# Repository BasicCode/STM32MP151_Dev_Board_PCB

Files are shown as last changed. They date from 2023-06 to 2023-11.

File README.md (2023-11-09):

# STM32MP151 Dev Board
**Rev B**
  
**NOTE: There are issues with this board. The WiFi, and the sound do not work (yes, that's basically all of the peripherals).**
  
**NOTE:** I have moved on from this project and it is no longer maintained. You can find some progress on my [STM32MP135 board](https://github.com/BasicCode/STM32MP135_Dev_Board_Buildroot).

A *minimal* STM32MP151 single-board-computer PCB, designed in KiCad, based on a [MYiR SoM](https://au.mouser.com/ProductDetail/MYIR/MYC-YA151C-256N256D-65-C-T?qs=e8oIoAS2J1SxKfhSw3h3gA%3D%3D). This project is intended as a minimal implementation of an ARM based Linux system used for learning Buildroot, the Linux kernel, the device tree system, and PCB design. The design uses hand-solderable parts (intermediate skill level), a 2-layer PCB design which can be manufactured by any PCB manufacturer, and a minimal set of peripherals.
  
**NOTE** that this project is a learning process and I a have no professional experience with PCB layout - don't use this as a reference design. That said, if it works for your purpose, please feel free to modify or use it.

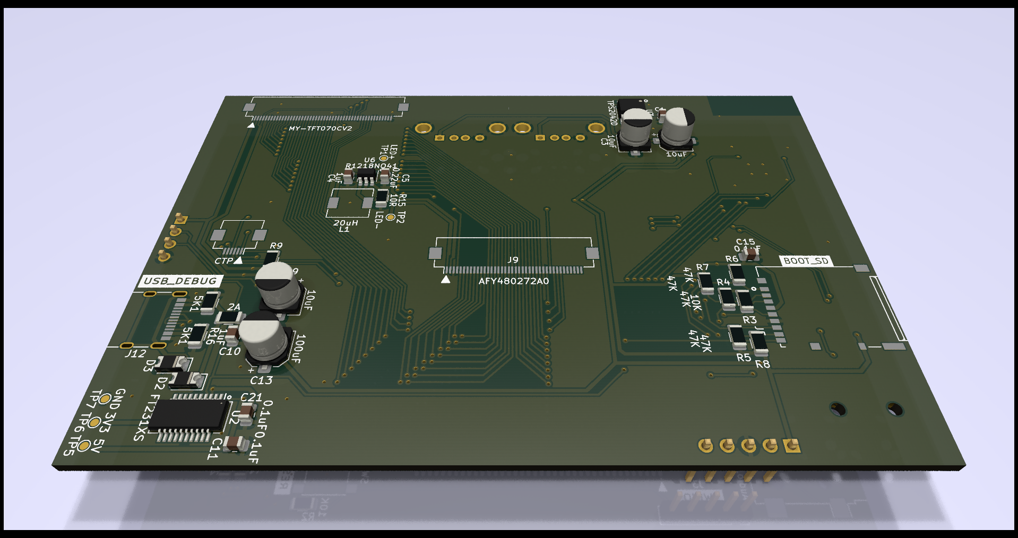
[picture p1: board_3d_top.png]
Citcuit Board

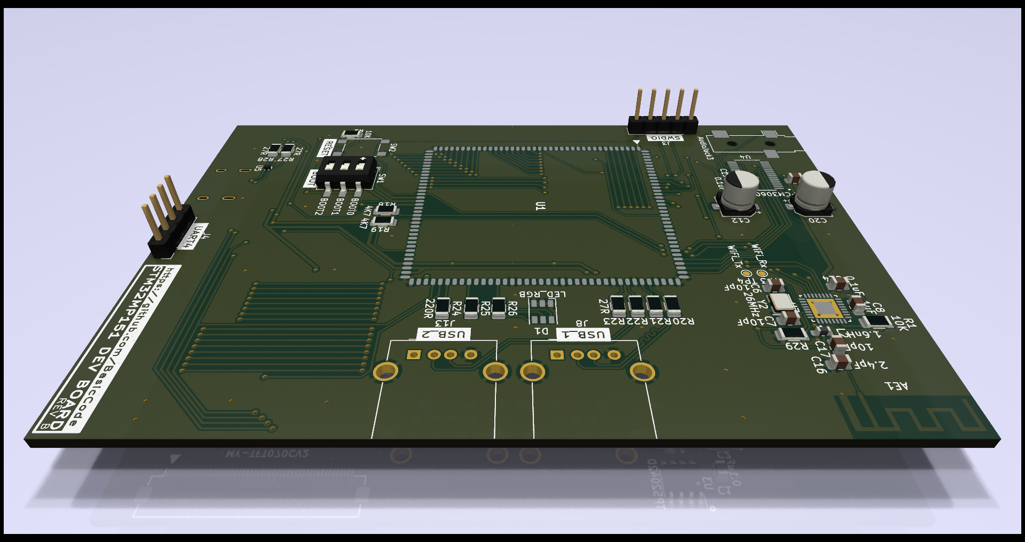
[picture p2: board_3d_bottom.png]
Circuit Board


## Software

* [Buildroot external tree](https://github.com/BasicCode/STM32MP15x_Dev_Board)

## Hardware

* [Schematic](schematic.pdf)
* [PCB available from OSH Park](https://oshpark.com/shared_projects/CuSocwHZ)
* [Parts list](https://www.digikey.com.au/en/mylists/list/Z7PZFZ0LWC)

### Specifications
* STM32MP151 ARM Cortex A7 running at 650MHz
* 256MB DDR3 RAM
* 256MB NAND Flash (not used in this example)
* 4.3-inch, OR 7-inch LCD with touch
* 2x USB 2.0 host ports
* USB-C power and serial port
* Wifi
* 3.5mm Audio Out

### Parts
A parts list is available on Digikey with **most** of the components, as well as the included [BoM file](STM32MP151_Dev_Board.csv). Please double check the Digikey parts list against the BoM before ordering, in case some components are missing. The [MYiR SoM](https://au.mouser.com/ProductDetail/MYIR/MYC-YA151C-256N256D-65-C-T?qs=e8oIoAS2J1SxKfhSw3h3gA%3D%3D) is only available from Mouser or directly from the manufacturer.

## Assembly
Components can be soldered by hand with some difficulty and patience. Some peripherals which are more difficult to solder (like WiFi), or not needed, can be left unpopulated. The minimum working example for this system is just the system-on-module, and the *UART* or *SWDIO* header, however this isn't very useful or interesting and so the other peripherals are included for fun.

## Bugs
* WiFi chipset doesn't seem to work. I believe it is connected correctly, Linux seems to recognise the chip and attempt to load the driver, however the driver fails to load.
* The PCM3060 audio chipset has not been tested yet. May not even work.

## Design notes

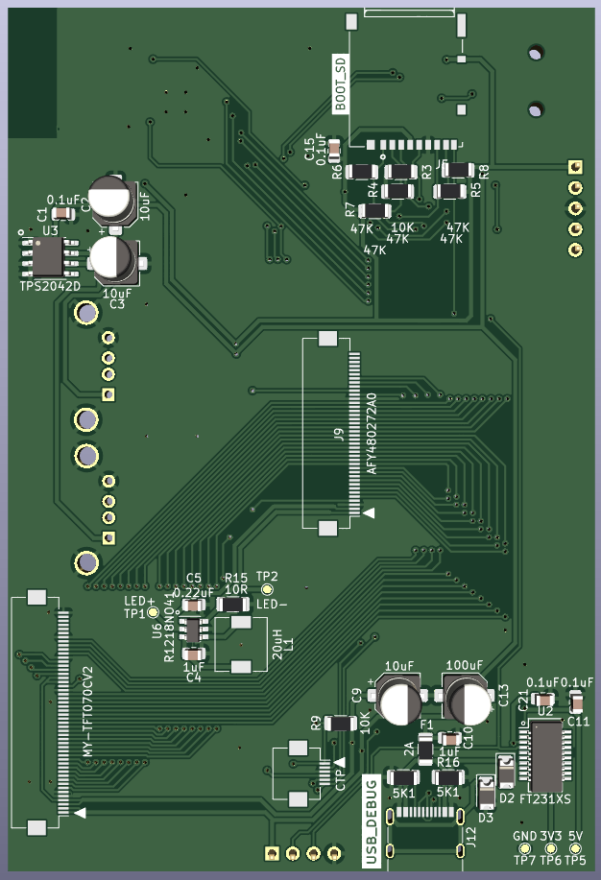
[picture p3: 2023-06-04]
board_top.png

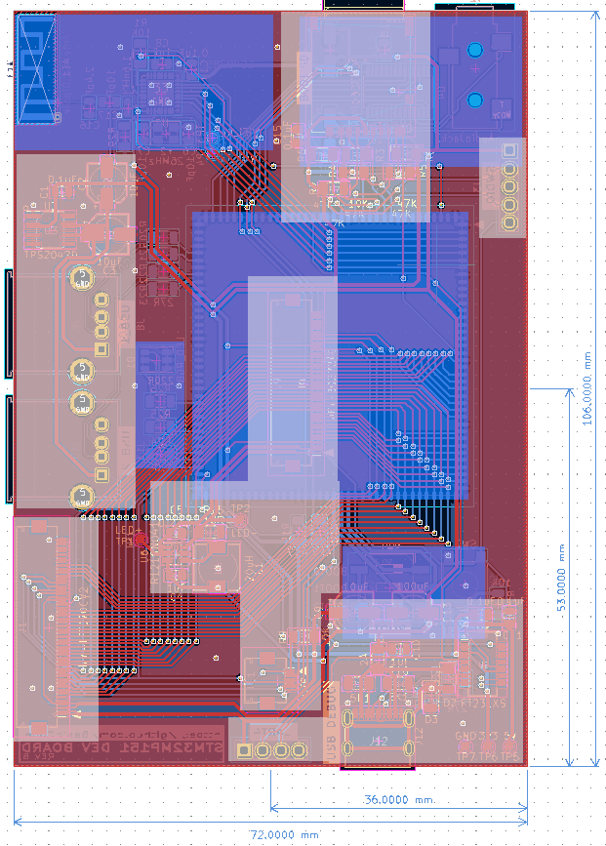
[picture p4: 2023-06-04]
board_map.png

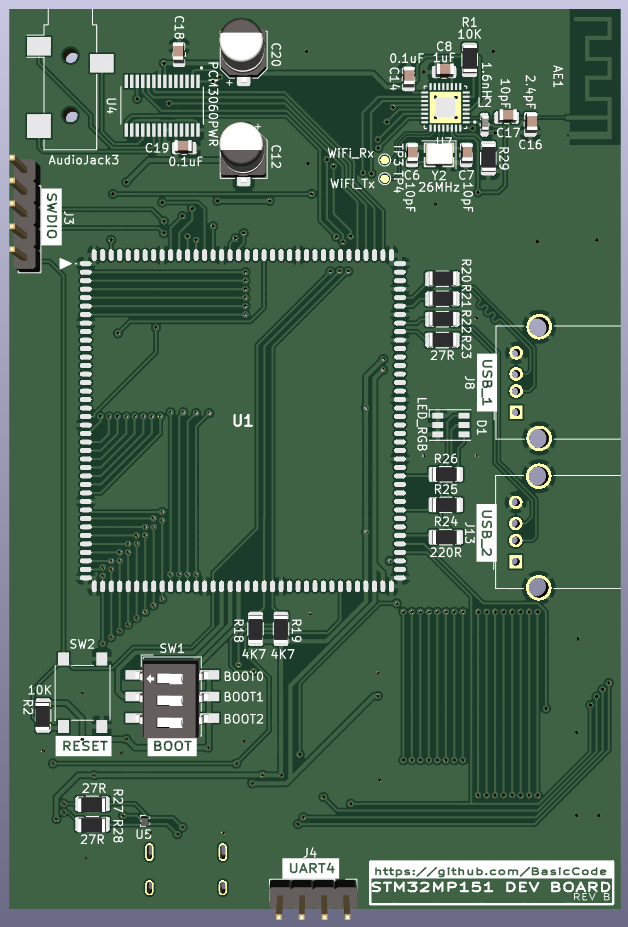
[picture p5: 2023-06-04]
board_bottom.png

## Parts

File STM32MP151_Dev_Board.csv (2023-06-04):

Source: | C:\Users\tommy\OneDrive\Documents\KiCad\STM32MP151_Dev_Board_RevB\STM32MP151_Dev_Board.kicad_sch
Date: | 3/06/2023 5:22:46 PM
Tool: | Eeschema 7.0.1
Generator: | C:\Program Files\KiCad\7.0\bin\scripting\plugins/bom_csv_grouped_by_value_with_fp.py
Component Count: | 79
Ref | Qnty | Value | Cmp name | Footprint | Description | Vendor | DNP
AE1 | 1 | Antenna_Dipole | Antenna_Dipole | RF_Antenna:Texas_SWRA117D_2.4GHz_Left | Dipole antenna
C1, C11, C14, C15, C18, C19, C21 | 7 | 0.1uF | C | Capacitor_SMD:C_0805_2012Metric | Unpolarized capacitor
C2, C3, C9, C12, C20 | 5 | 10uF | C_Polarized | Capacitor_SMD:CP_Elec_5x5.3 | Polarized capacitor
C4, C8, C10 | 3 | 1uF | C | Capacitor_SMD:C_0805_2012Metric | Unpolarized capacitor
C5 | 1 | 0.22uF | C | Capacitor_SMD:C_0805_2012Metric | Unpolarized capacitor
C6, C7, C17 | 3 | 10pF | C | Capacitor_SMD:C_0805_2012Metric | Unpolarized capacitor
C13 | 1 | 100uF | C_Polarized | Capacitor_SMD:CP_Elec_5x5.3 | Polarized capacitor
C16 | 1 | 2.4pF | C | Capacitor_SMD:C_0805_2012Metric | Unpolarized capacitor
D1 | 1 | LED_RGB | LED_RGB | LED_SMD:LED_RGB_PLCC-6 | RGB LED, 6 pin package
D2, D3 | 2 | TVS | D_Schottky | Diode_SMD:D_1206_3216Metric | Schottky diode
F1 | 1 | 2A | Polyfuse | Fuse:Fuse_1206_3216Metric | Resettable fuse, polymeric positive temperature coefficient
J1 | 1 | MY-TFT070CV2 | Conn_02x25_Odd_Even | Connector_FFC-FPC:Hirose_FH12-50S-0.5SH_1x50-1MP_P0.50mm_Horizontal | Generic connector, double row, 02x25, odd/even pin numbering scheme (row 1 odd numbers, row 2 even numbers), script generated (kicad-library-utils/schlib/autogen/connector/)
J2 | 1 | AudioJack3 | AudioJack3 | Connector_Audio:Jack_3.5mm_CUI_SJ-3523-SMT_Horizontal | Audio Jack, 3 Poles (Stereo / TRS)
J3 | 1 | SWDIO | Conn_01x05_Pin | Connector_PinHeader_2.54mm:PinHeader_1x05_P2.54mm_Vertical | Generic connector, single row, 01x05, script generated
J4 | 1 | UART4 | Conn_01x04_Pin | Connector_PinHeader_2.54mm:PinHeader_1x04_P2.54mm_Vertical | Generic connector, single row, 01x04, script generated
J5 | 1 | BOOT_SD | DM3AT-SF-PEJM5 | MYC_YA151:HRS_DM3AT-SF-PEJM5
J8 | 1 | USB_1 | USB_A | Connector_USB:USB_A_Molex_67643_Horizontal | USB Type A connector
J9 | 1 | AFY480272A0 | Conn_01x40 | Connector_FFC-FPC:Hirose_FH12-40S-0.5SH_1x40-1MP_P0.50mm_Horizontal | Generic connector, single row, 01x40, script generated (kicad-library-utils/schlib/autogen/connector/)
J11 | 1 | CTP | Conn_01x06 | Connector_FFC-FPC:Hirose_FH12-6S-0.5SH_1x06-1MP_P0.50mm_Horizontal | Generic connector, single row, 01x06, script generated (kicad-library-utils/schlib/autogen/connector/)
J12 | 1 | USB_DEBUG | USB_C_Receptacle_USB2.0 | Connector_USB:USB_C_Receptacle_G-Switch_GT-USB-7010ASV | USB 2.0-only Type-C Receptacle connector
J13 | 1 | USB_2 | USB_A | Connector_USB:USB_A_Molex_67643_Horizontal | USB Type A connector
L1 | 1 | 20uH | L | Inductor_SMD:L_6.3x6.3_H3 | Inductor
L2 | 1 | 1.6nH | L | Inductor_SMD:L_0603_1608Metric_Pad1.05x0.95mm_HandSolder | Inductor
R1, R2, R3, R9 | 4 | 10K | R | Resistor_SMD:R_1206_3216Metric | Resistor
R4, R5, R6, R7, R8 | 5 | 47K | R | Resistor_SMD:R_1206_3216Metric | Resistor
R15 | 1 | 10R | R | Resistor_SMD:R_1206_3216Metric | Resistor
R16, R17 | 2 | 5K1 | R | Resistor_SMD:R_1206_3216Metric | Resistor
R18, R19 | 2 | 4K7 | R | Resistor_SMD:R_1206_3216Metric | Resistor
R20, R21, R22, R23, R27, R28 | 6 | 27R | R | Resistor_SMD:R_1206_3216Metric | Resistor
R24, R25, R26 | 3 | 220R | R | Resistor_SMD:R_1206_3216Metric | Resistor
R29 | 1 | 12K | R | Resistor_SMD:R_1206_3216Metric | Resistor
SW1 | 1 | BOOT | SW_DIP_x03 | Button_Switch_SMD:SW_DIP_SPSTx03_Slide_6.7x9.18mm_W8.61mm_P2.54mm_LowProfile | 3x DIP Switch, Single Pole Single Throw (SPST) switch, small symbol
SW2 | 1 | RESET | SW_Push | Button_Switch_SMD:SW_Push_1P1T_NO_6x6mm_H9.5mm | Push button switch, generic, two pins
TP1 | 1 | LED+ | TestPoint | TestPoint:TestPoint_Pad_D1.0mm | test point
TP2 | 1 | LED- | TestPoint | TestPoint:TestPoint_Pad_D1.0mm | test point
TP3 | 1 | WiFi_Rx | TestPoint | TestPoint:TestPoint_Pad_D1.0mm | test point
TP4 | 1 | WiFi_Tx | TestPoint | TestPoint:TestPoint_Pad_D1.0mm | test point
TP5 | 1 | 5V | TestPoint | TestPoint:TestPoint_Pad_D1.0mm | test point
TP6 | 1 | 3V3 | TestPoint | TestPoint:TestPoint_Pad_D1.0mm | test point
TP7 | 1 | GND | TestPoint | TestPoint:TestPoint_Pad_D1.0mm | test point
U1 | 1 | MYC-YA151C-256N256D | MYC-YA151C-256N256D-65-C-T | MYC_YA151:MYCYA151C256N256D65CT | Embedded Module ARM Cortex-A7, ARM Cortex-M4 650MHz 256MB 256MB
U2 | 1 | FT231XS | FT231XS | Package_SO:SSOP-20_3.9x8.7mm_P0.635mm | Full Speed USB to Full Handshake UART, SSOP-20
U3 | 1 | TPS2042D | TPS2042D | Package_SO:SOIC-8_3.9x4.9mm_P1.27mm | Dual power-distribution switcher
U4 | 1 | PCM3060PWR | PCM3060PWR | PCM3060:SOP65P640X120-28N
U5 | 1 | TPD2EUSB30 | TPD2EUSB30 | Package_TO_SOT_SMD:Texas_DRT-3 | 2-Channel ESD Protection for Super-Speed USB 3.0 Interface, DRT-3
U6 | 1 | R1218NO41 | Conn_02x03_Counter_Clockwise | Package_TO_SOT_SMD:SOT-23-6 | Generic connector, double row, 02x03, counter clockwise pin numbering scheme (similar to DIP package numbering), script generated (kicad-library-utils/schlib/autogen/connector/)
U7 | 1 | ESP8285 | ESP8285 | esp8285:QFN50P500X500X90-33N
Y2 | 1 | 26MHz | Crystal_GND24 | Crystal:Crystal_SMD_3225-4Pin_3.2x2.5mm | Four pin crystal, GND on pins 2 and 4

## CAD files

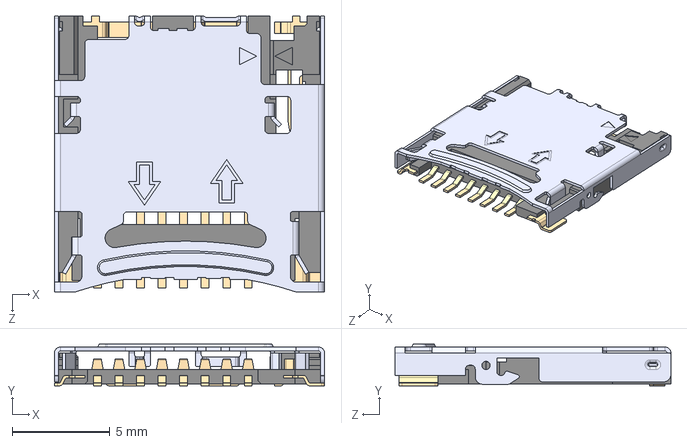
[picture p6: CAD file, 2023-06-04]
components/DM3CS-SF.step
13.8 x 2.13 x 14.1 mm

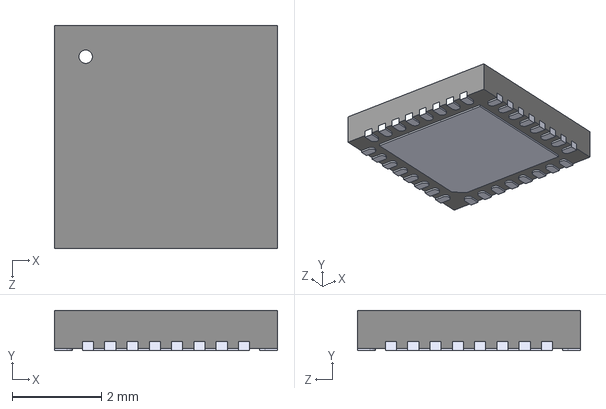
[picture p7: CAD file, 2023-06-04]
components/ESP8285.step
5.00 x 0.9 x 5.00 mm

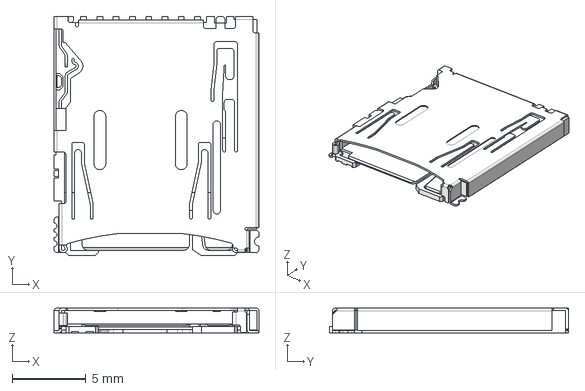
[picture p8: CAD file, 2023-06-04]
components/DM3AT-SF-PEJM5.step
13.8 x 16.2 x 1.68 mm

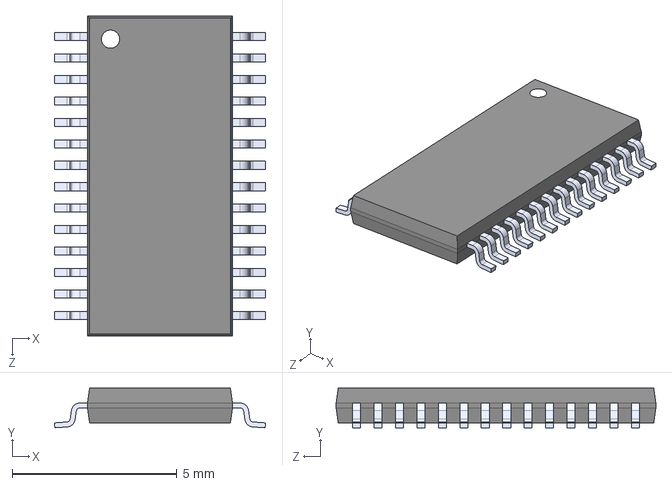
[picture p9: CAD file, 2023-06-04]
components/PCM3060PWR.step
6.40 x 1.20 x 9.70 mm

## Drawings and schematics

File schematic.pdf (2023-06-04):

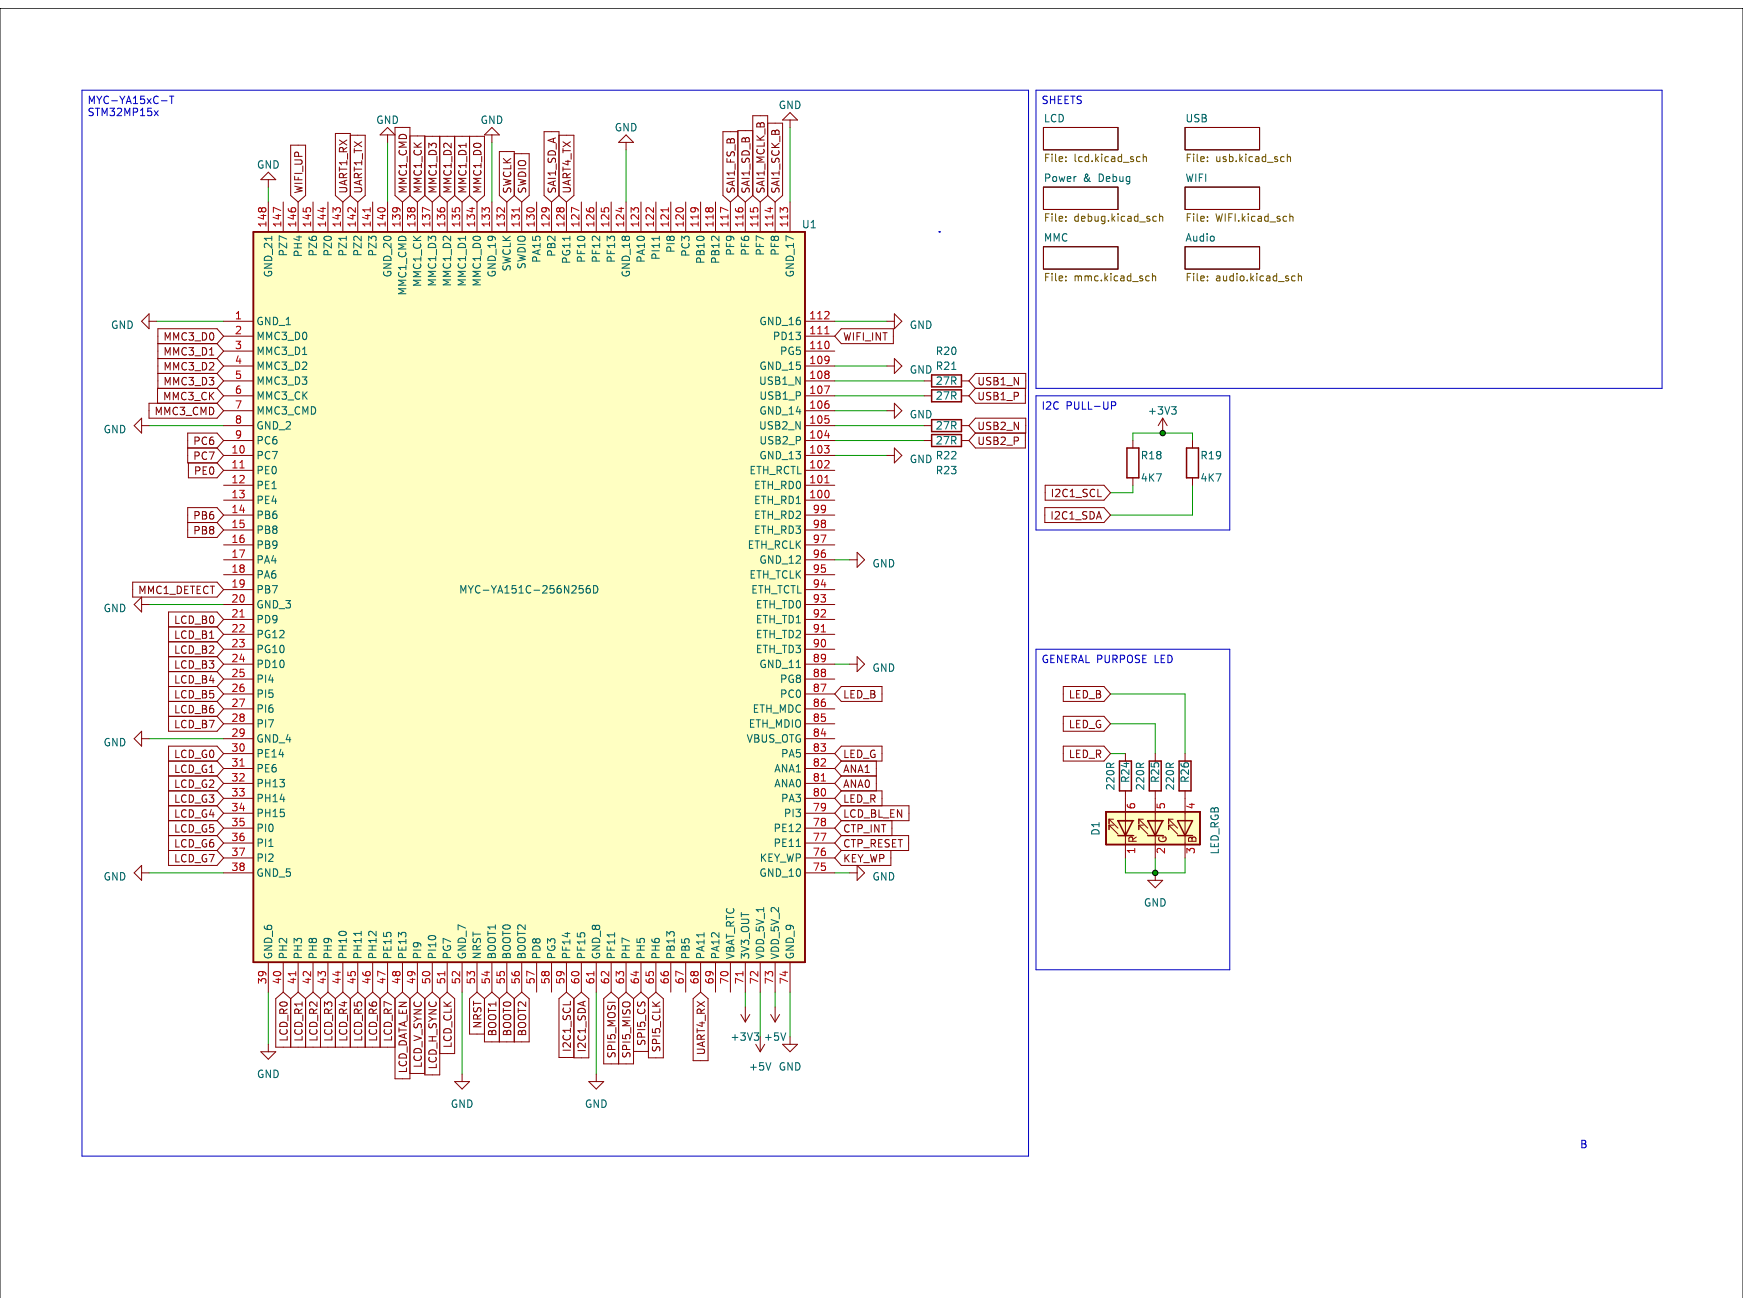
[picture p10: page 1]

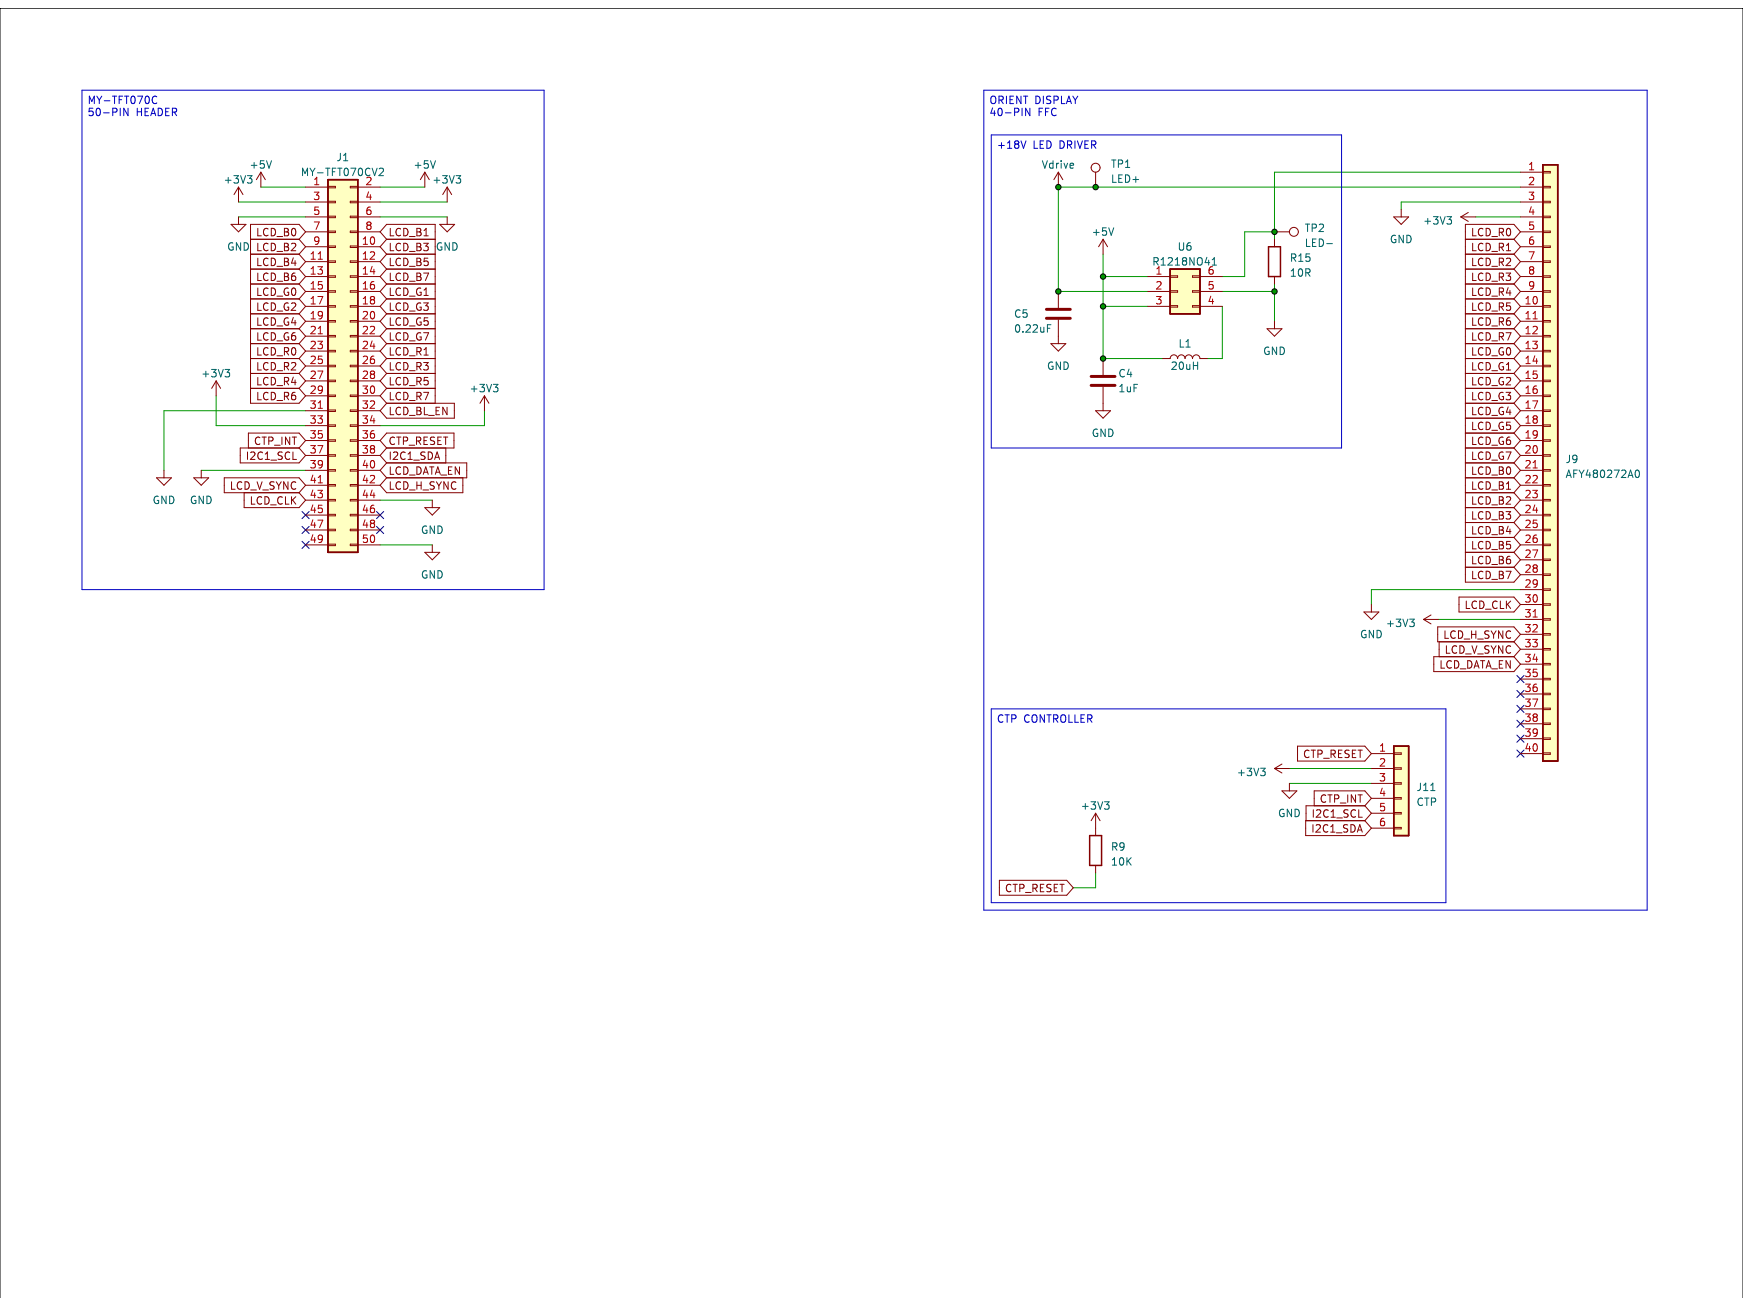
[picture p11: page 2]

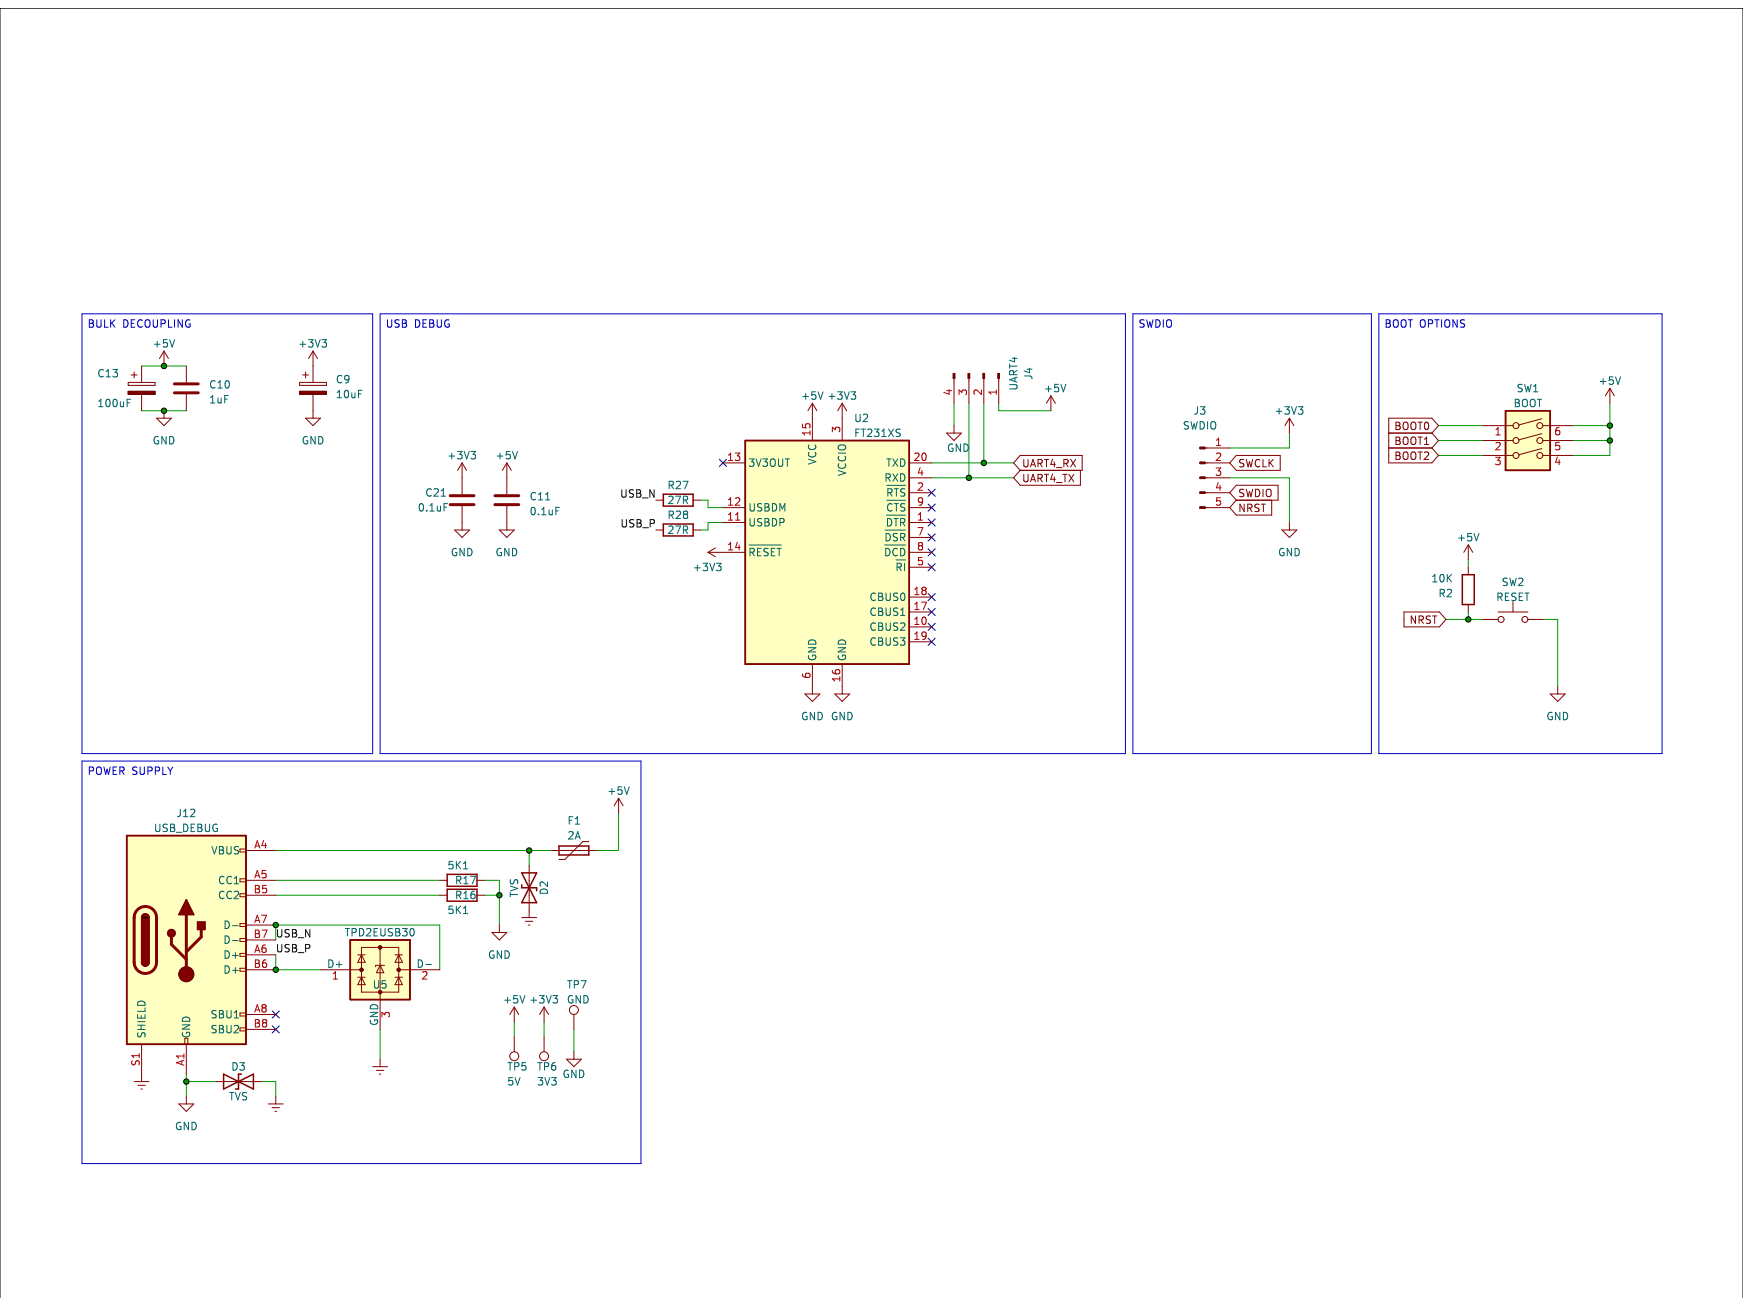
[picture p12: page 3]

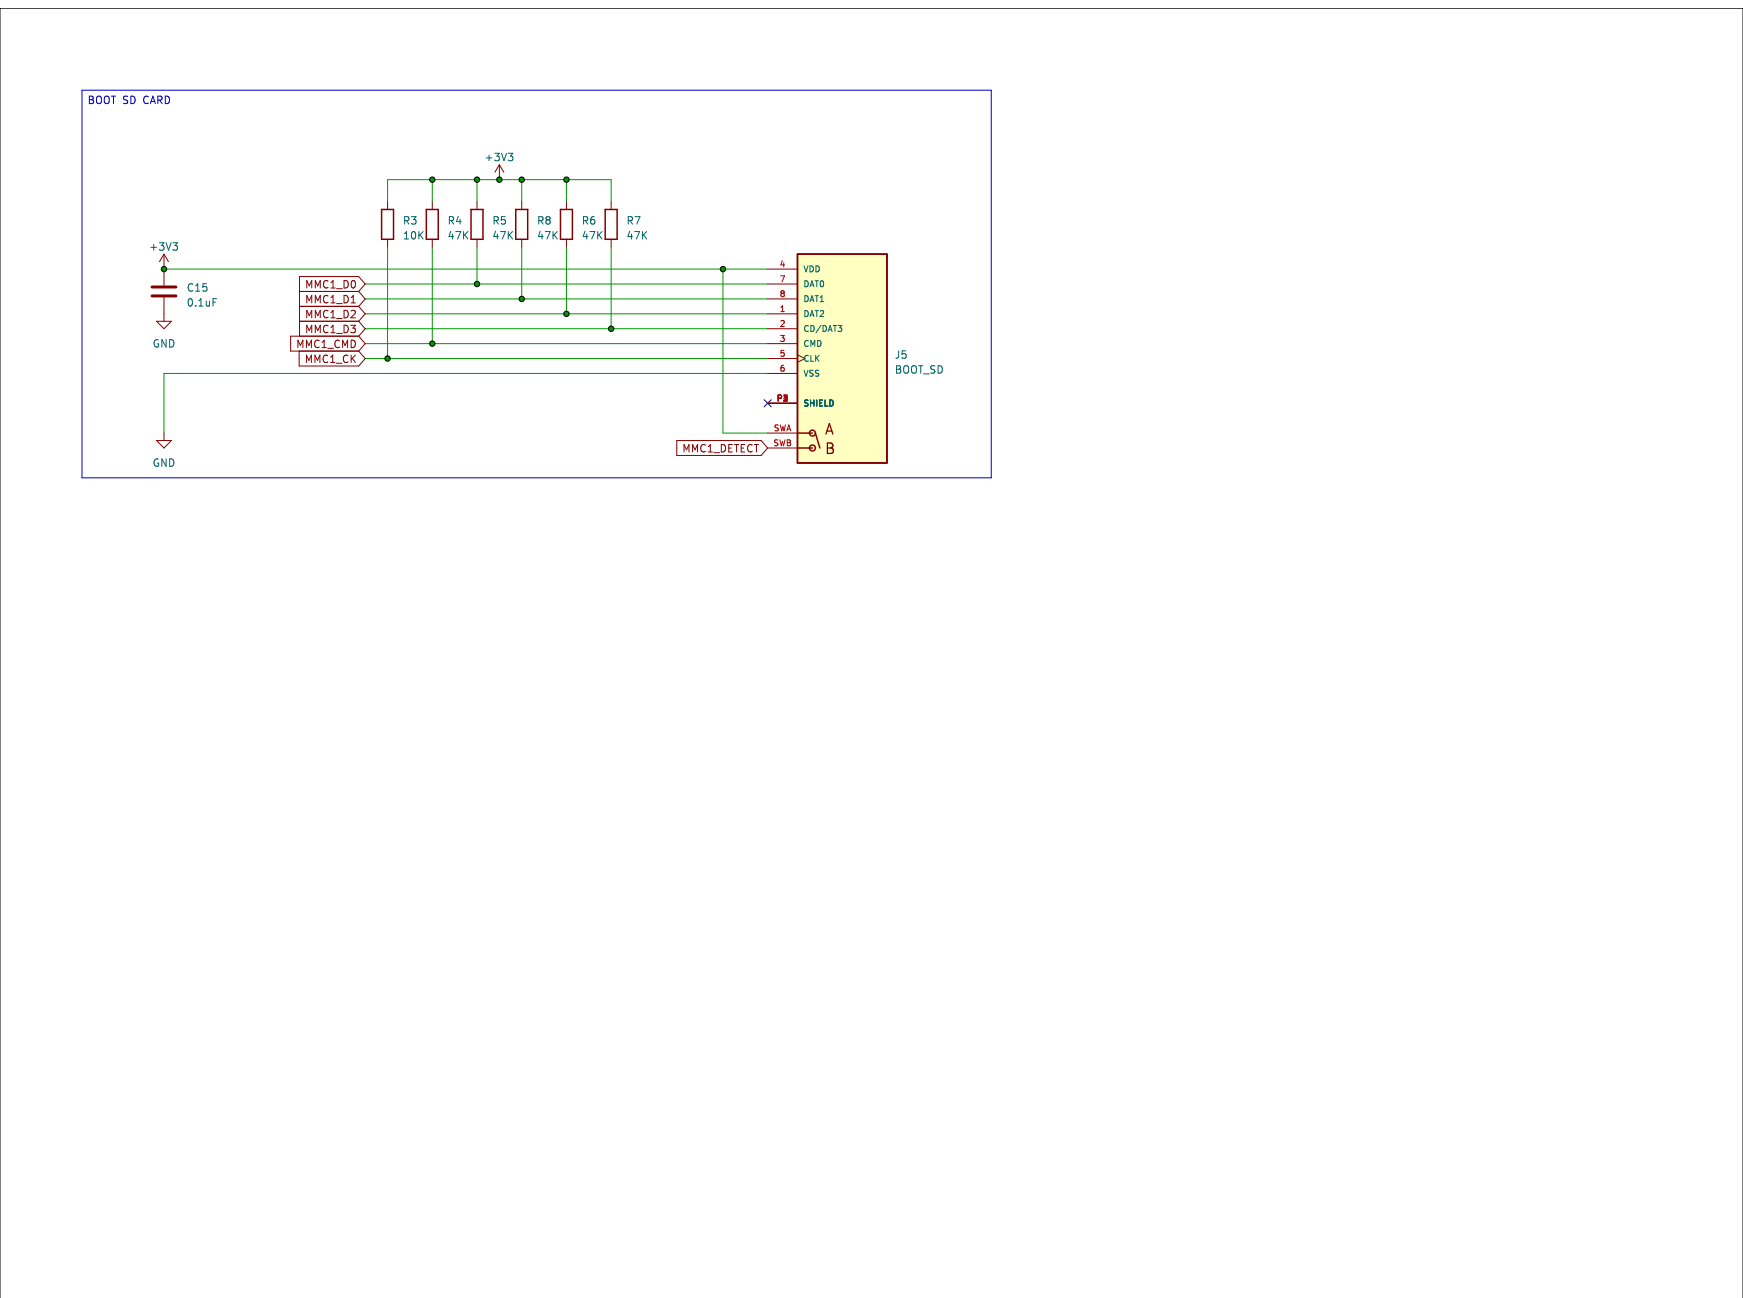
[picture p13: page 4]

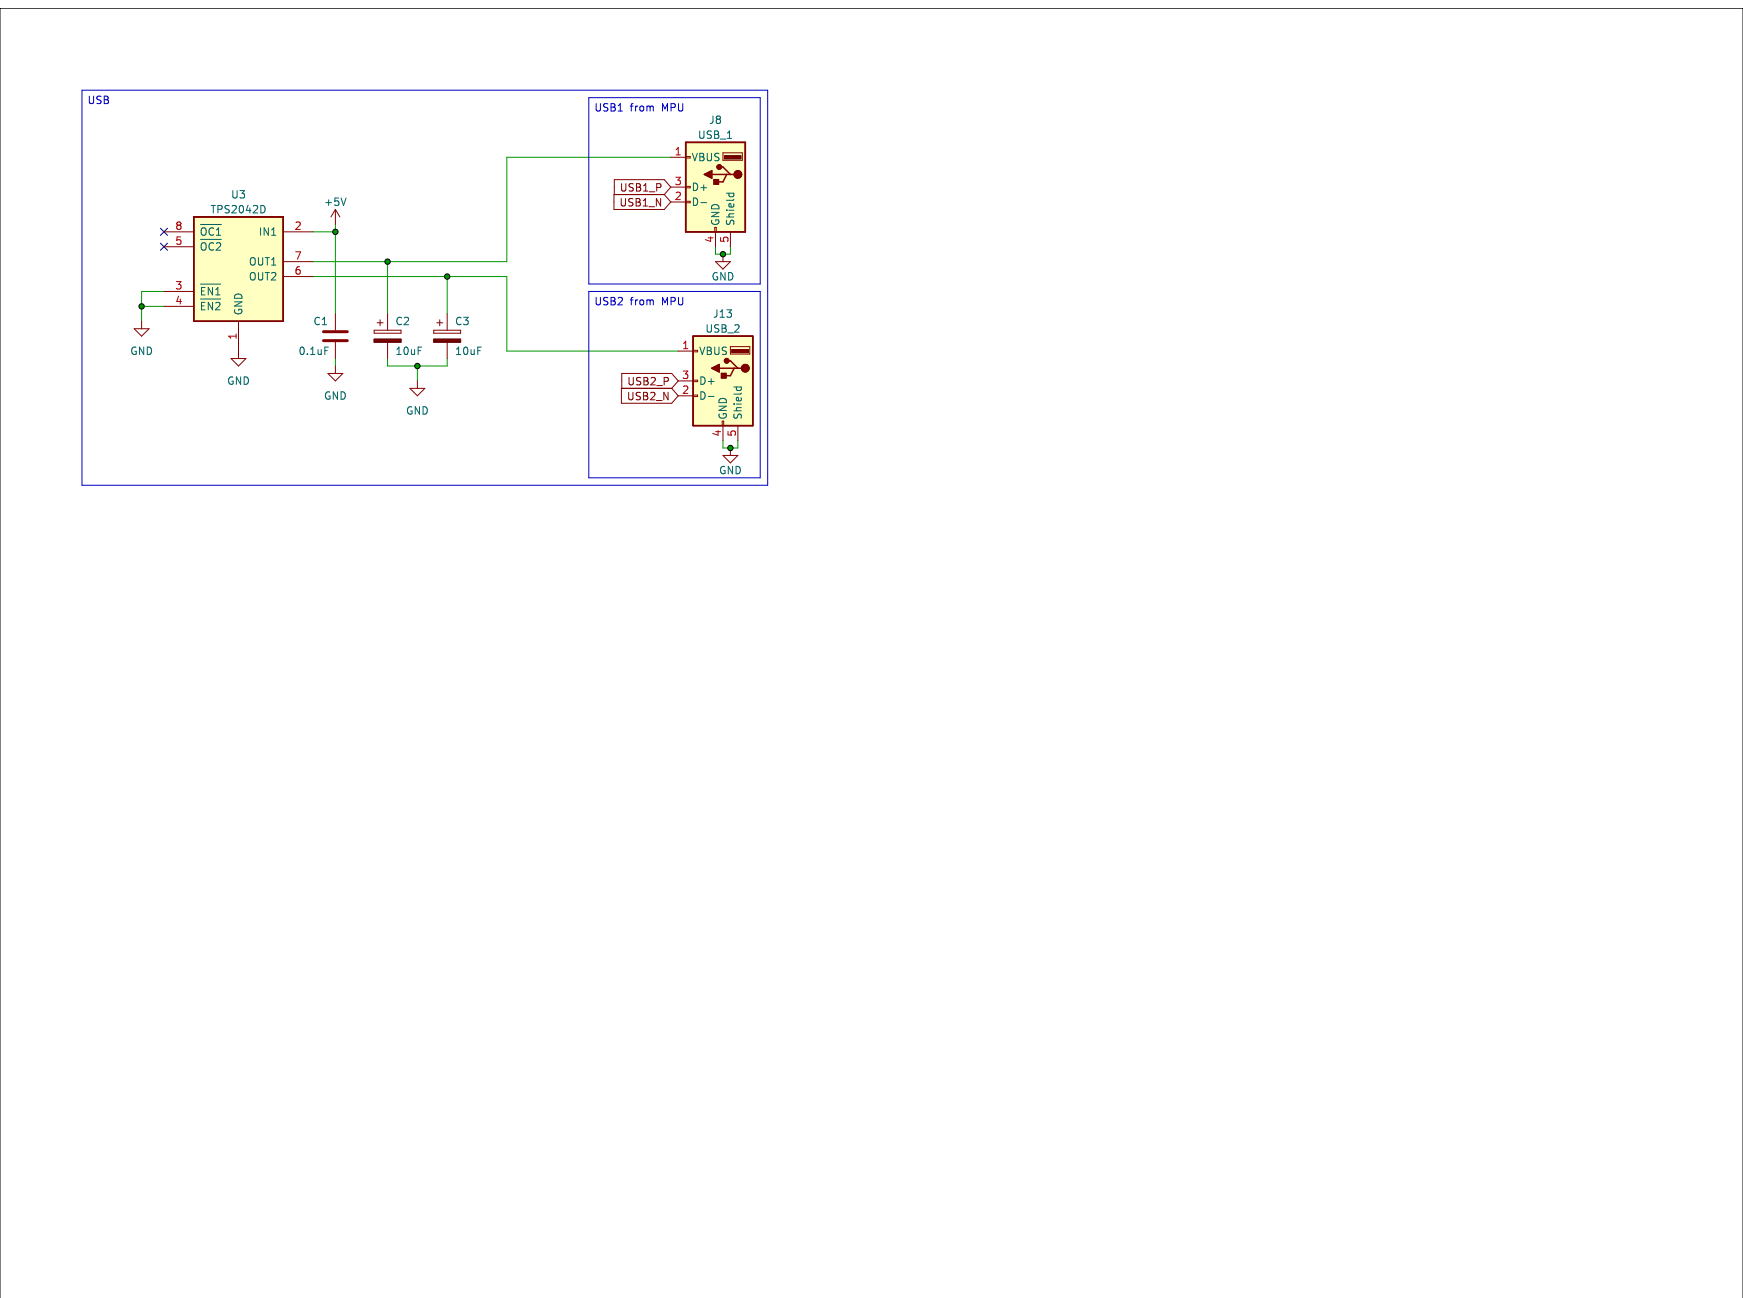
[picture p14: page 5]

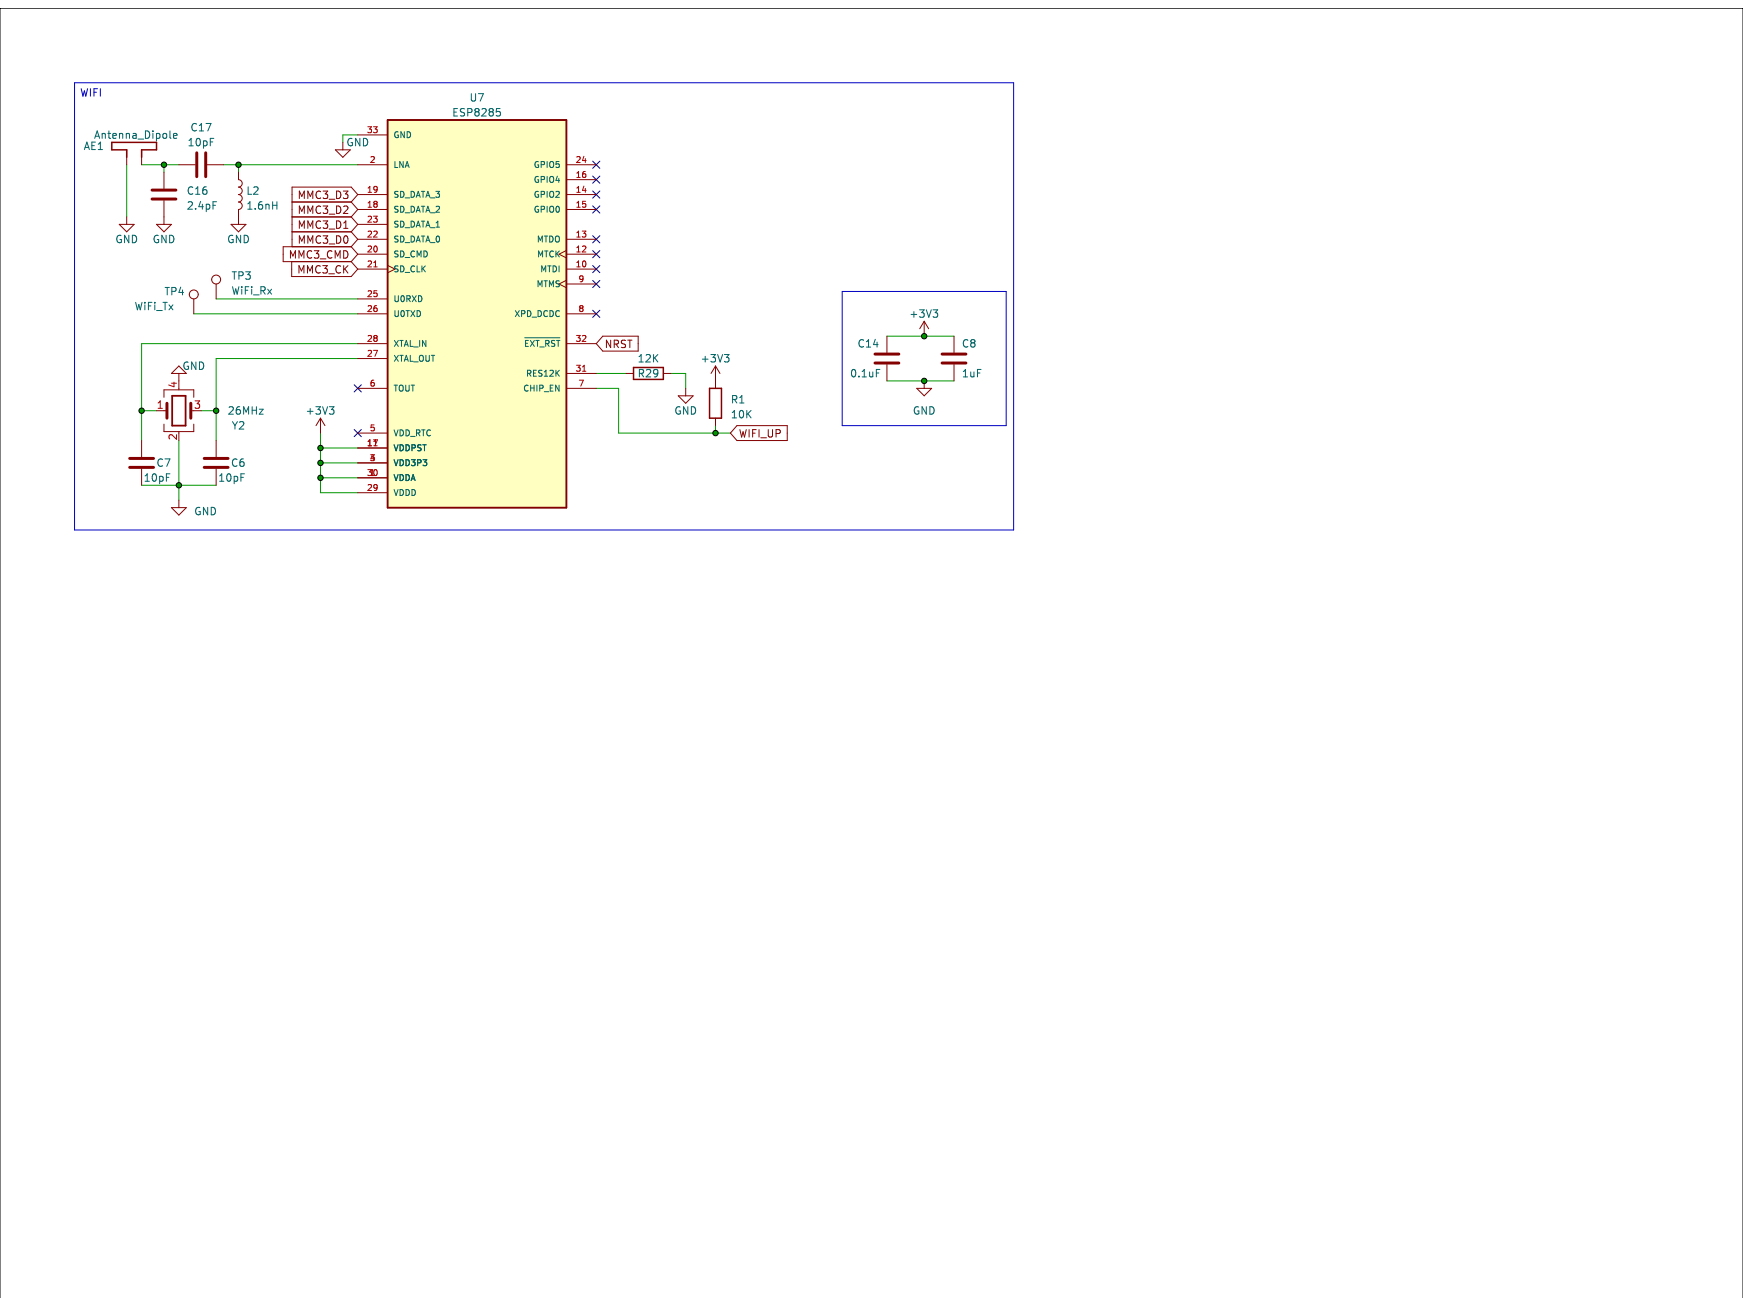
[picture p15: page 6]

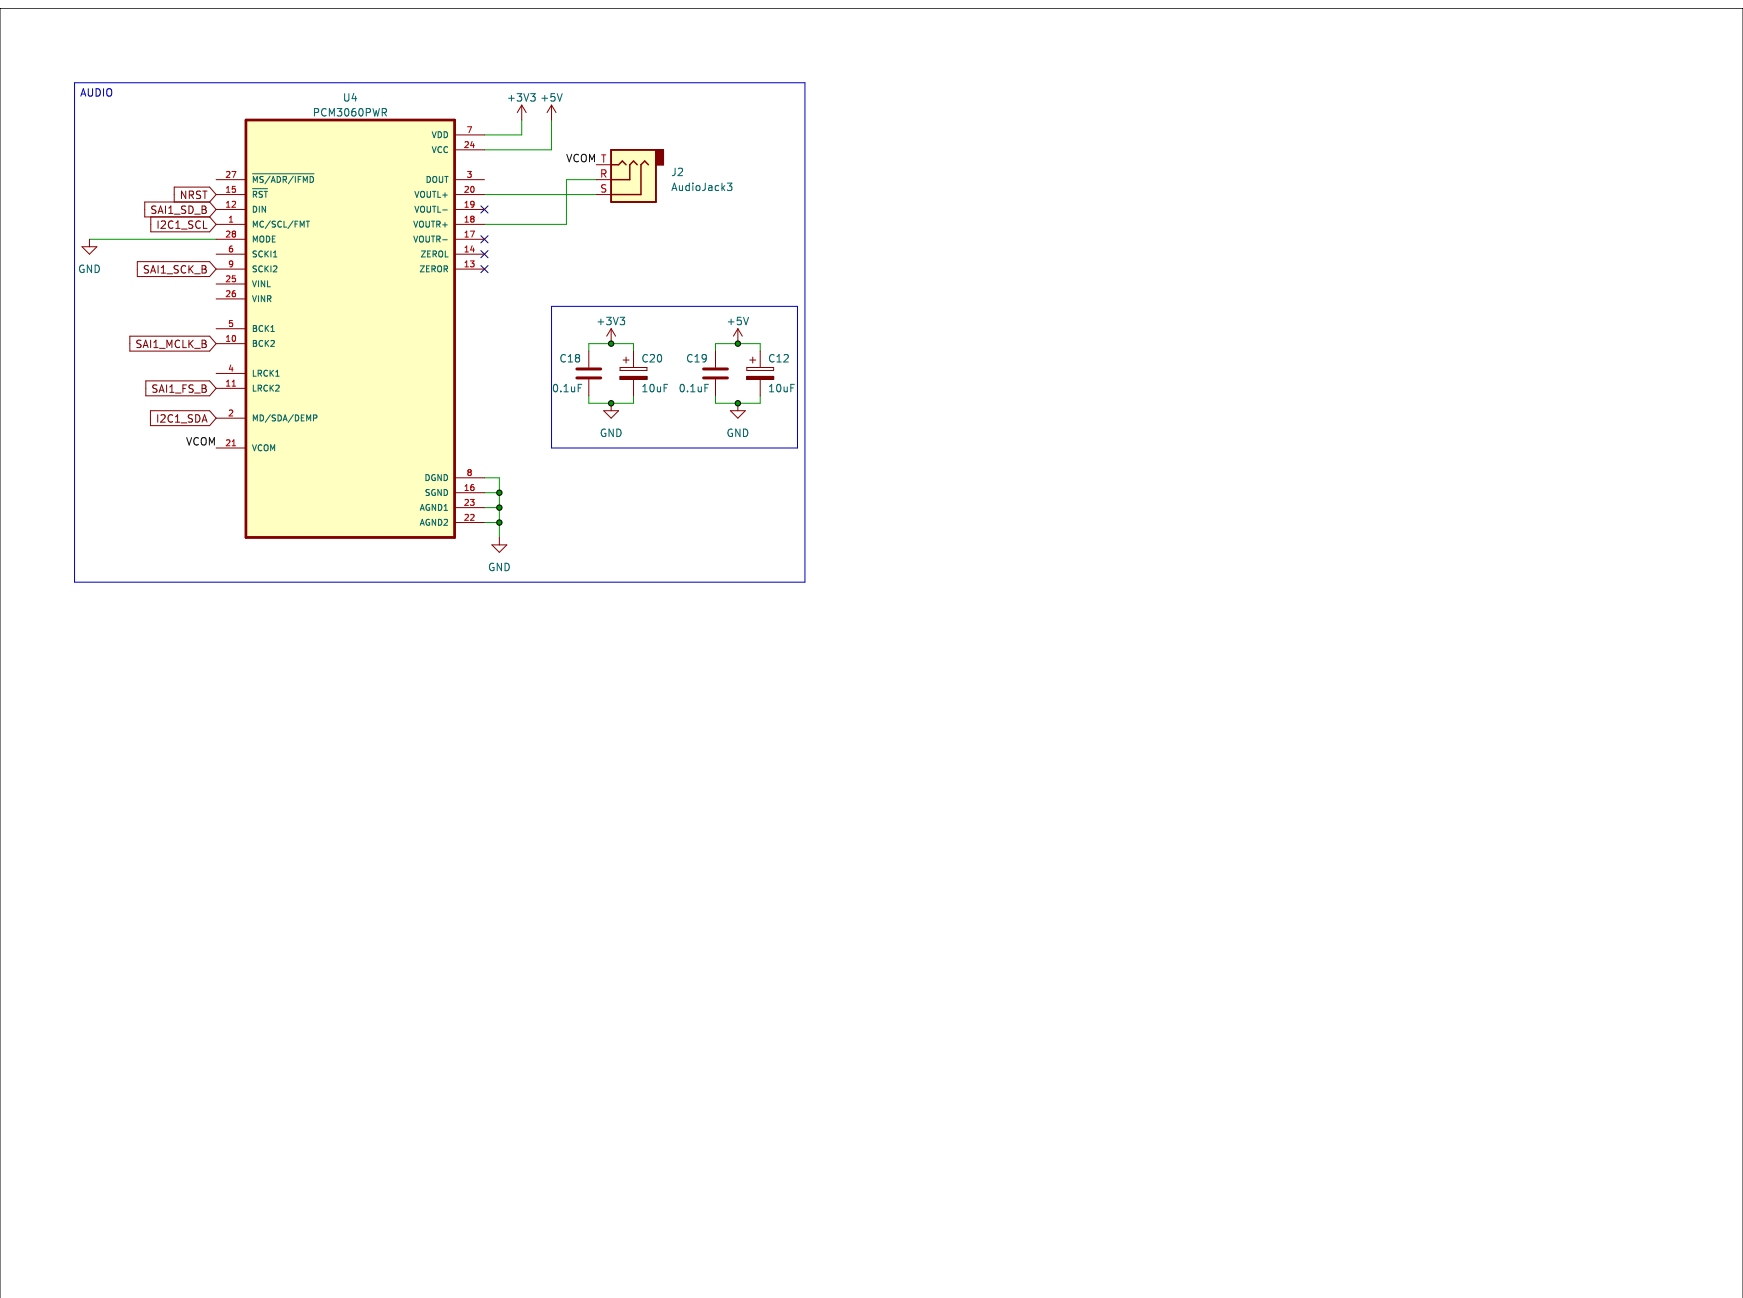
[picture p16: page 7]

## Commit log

2023-06-04 add schematic
2023-08-02 Included board errors
2023-08-06 fix swapped SAI clock signals
    [audio.kicad_sch, power.kicad_sch]
2023-08-06 swap SAI clock signals. UPdate rev numbmer
    [STM32MP151_Dev_Board.kicad_pcb]
2023-08-09 update gerber files
    [STM32MP151_Dev_Board-B_Cu.gbr, STM32MP151_Dev_Board-B_Mask.gbr, STM32MP151_Dev_Board-B_Paste.gbr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]
